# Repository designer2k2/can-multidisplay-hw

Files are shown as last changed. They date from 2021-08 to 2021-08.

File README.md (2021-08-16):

# can-multidisplay-hw
Displaying and measuring automotive related values, with CAN, GPS and more

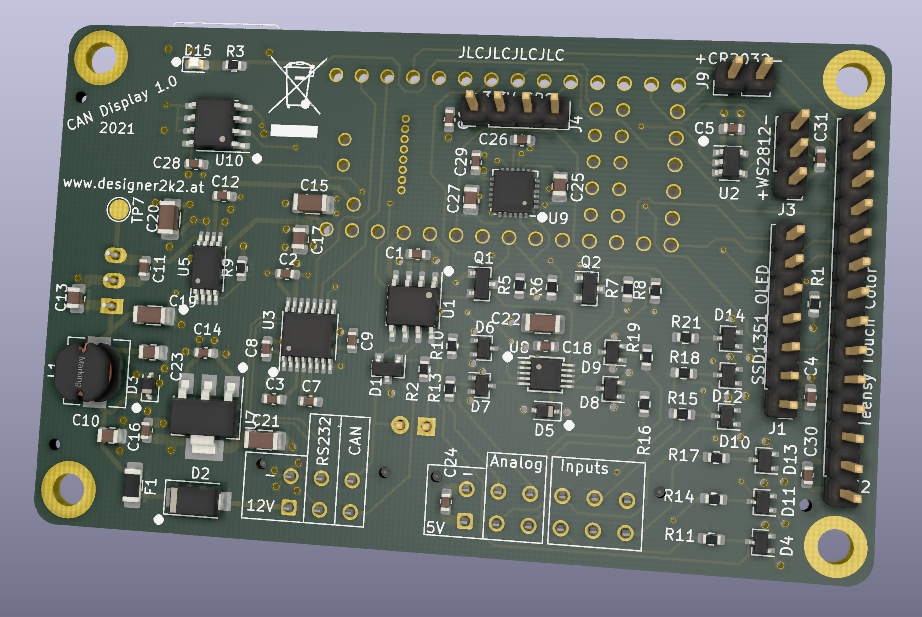
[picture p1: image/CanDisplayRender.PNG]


Software: https://github.com/designer2k2/can-multidisplay

## Features:

* Teensy 4 Microcontroller https://www.pjrc.com/store/teensy40.html
* 12V -> 5V Power supply with TPS2113A voltage selector
* 3,3V Power supply
* RTC battery to support Teensy
* SD card slot, with flex cable to Teensy
* WS2812 level shifter 74AHCT1G125
* GPS serial port
* CAN transceiver SN65HVD232 with selectable 120Ohm resistor
* RS232 level shifter MAX3232
* MPU-6050  Six-Axis (Gyro + Accelerometer)
* I2C Levelshifter to 5V
* TMP75AIDR I2C Temperature sensor
* 4 channel 12Bit ADC ADS1015IDGS
* 6 protected inputs
* SSD1351 OLED  Interface
* ILI9341 + XPT2046 Touch display Interface

PCB is made in KiCad and parts selected to have it produced by JLCPCB

## Images:

PCB Backside:

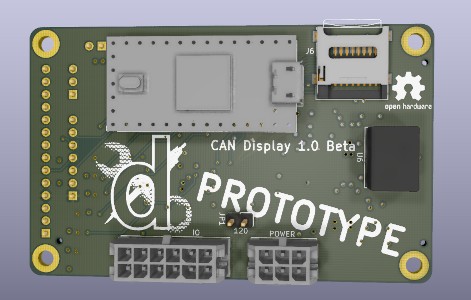
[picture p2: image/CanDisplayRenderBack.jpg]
PCB Backside


3D Rendering with Display, GPS and RGB LED:

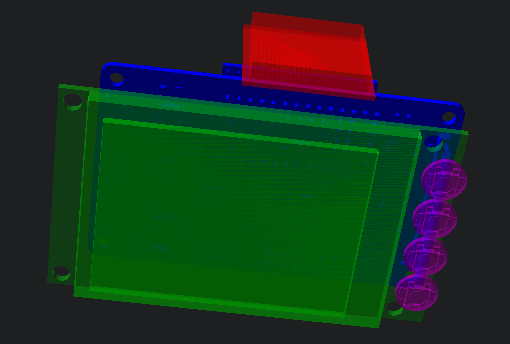
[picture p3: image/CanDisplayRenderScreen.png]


Display running:

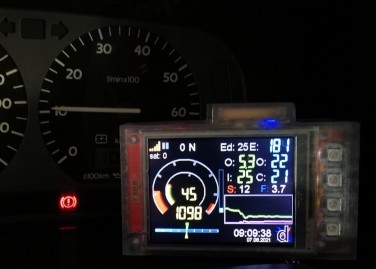
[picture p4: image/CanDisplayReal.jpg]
Display running


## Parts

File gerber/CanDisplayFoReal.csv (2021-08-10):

Comment | Designator | Footprint | LCSC
100n | C1,C2,C3,C4,C5,C6,C7,C8,C9,C11,C12,C14,C16,C18,C24,C26,C28,C29,C30,C31 | Capacitor_SMD:C_0603_1608Metric | C14663
2.2u | C10,C13 | Capacitor_SMD:C_0805_2012Metric | C49217
10u | C15,C19,C20,C21,C22 | Capacitor_SMD:C_1206_3216Metric | C13585
10n | C17,C23,C25 | Capacitor_SMD:C_0805_2012Metric | C1710
2.2n | C27 | Capacitor_SMD:C_0805_2012Metric | C28260
SZNUP2105L | D1 | Package_TO_SOT_SMD:SOT-23 | C233494
LED | D15 | LED_SMD:LED_0603_1608Metric | C2286
SK34 | D2 | Diode_SMD:D_SMA | C65008
24V | D3 | Diode_SMD:D_SOD-323 | C463816
5.1V | D5 | Diode_SMD:D_SOD-323 | C85392
BAT54SW | D4,D6,D7,D8,D9,D10,D11,D12,D13,D14 | Package_TO_SOT_SMD:SOT-323_SC-70 | C78260
Polyfuse | F1 | Fuse:Fuse_1206_3216Metric_Castellated | C70082
SmallDisp | J1 | Connector_PinHeader_2.54mm:PinHeader_1x07_P2.54mm_Vertical
BigDisp | J2 | Connector_PinHeader_2.54mm:PinHeader_1x14_P2.54mm_Vertical
WS2812 | J3 | Connector_PinHeader_2.54mm:PinHeader_1x03_P2.54mm_Vertical
GPS | J4 | Connector_PinHeader_2.54mm:PinHeader_1x04_P2.54mm_Vertical
Main Connect | J5 | Connector_Molex:Molex_Micro-Fit_3.0_43045-0612_2x03_P3.00mm_Vertical
Micro_SD_Card | J6 | Connector_Card:microSD_HC_Wuerth_693072010801
I/O | J8 | Connector_Molex:Molex_Micro-Fit_3.0_43045-1212_2x06_P3.00mm_Vertical
Batt | J9 | Connector_PinHeader_2.54mm:PinHeader_1x02_P2.54mm_Vertical
120CAN | JP1 | Connector_PinHeader_2.54mm:PinHeader_1x02_P2.54mm_Vertical
68uH | L1 | Inductor_SMD:L_6.3x6.3_H3 | C86662
BSS138 | Q1,Q2 | Package_TO_SOT_SMD:SOT-23 | C52895
100 | R1 | Resistor_SMD:R_0603_1608Metric | C22775
1k | R10,R11,R13,R14,R15,R16,R17,R18,R19,R21 | Resistor_SMD:R_0603_1608Metric | C21190
120 | R2,R3 | Resistor_SMD:R_0603_1608Metric | C22787
10k | R5,R6,R7,R8 | Resistor_SMD:R_0603_1608Metric | C25804
500 | R9 | Resistor_SMD:R_0603_1608Metric | C22808
TestPoint | TP5,TP7 | TestPoint:TestPoint_Pad_D2.0mm
SN65HVD232 | U1 | Package_SO:SOIC-8_3.9x4.9mm_P1.27mm | C30530
TMP75AIDR | U10 | Package_SO:SOIC-8_3.9x4.9mm_P1.27mm | C30389
74AHCT1G125 | U2 | Package_TO_SOT_SMD:SOT-23-5 | C12494
MAX3232 | U3 | Package_SO:TSSOP-16_4.4x5mm_P0.65mm | C19767
Teensy4.0 | U4 | teensy:Teensy40_SMT
TPS2113A | U5 | Package_SO:TSSOP-8_4.4x3mm_P0.65mm | C130052
R-78HE5.0-0.3 | U6 | Converter_DCDC:Converter_DCDC_RECOM_R-78E-0.5_THT
AMS1117-3.3 | U7 | Package_TO_SOT_SMD:SOT-223-3_TabPin2 | C6186
ADS1015IDGS | U8 | Package_SO:TSSOP-10_3x3mm_P0.5mm | C193969
MPU-6050 | U9 | Sensor_Motion:InvenSense_QFN-24_4x4mm_P0.5mm | C24112

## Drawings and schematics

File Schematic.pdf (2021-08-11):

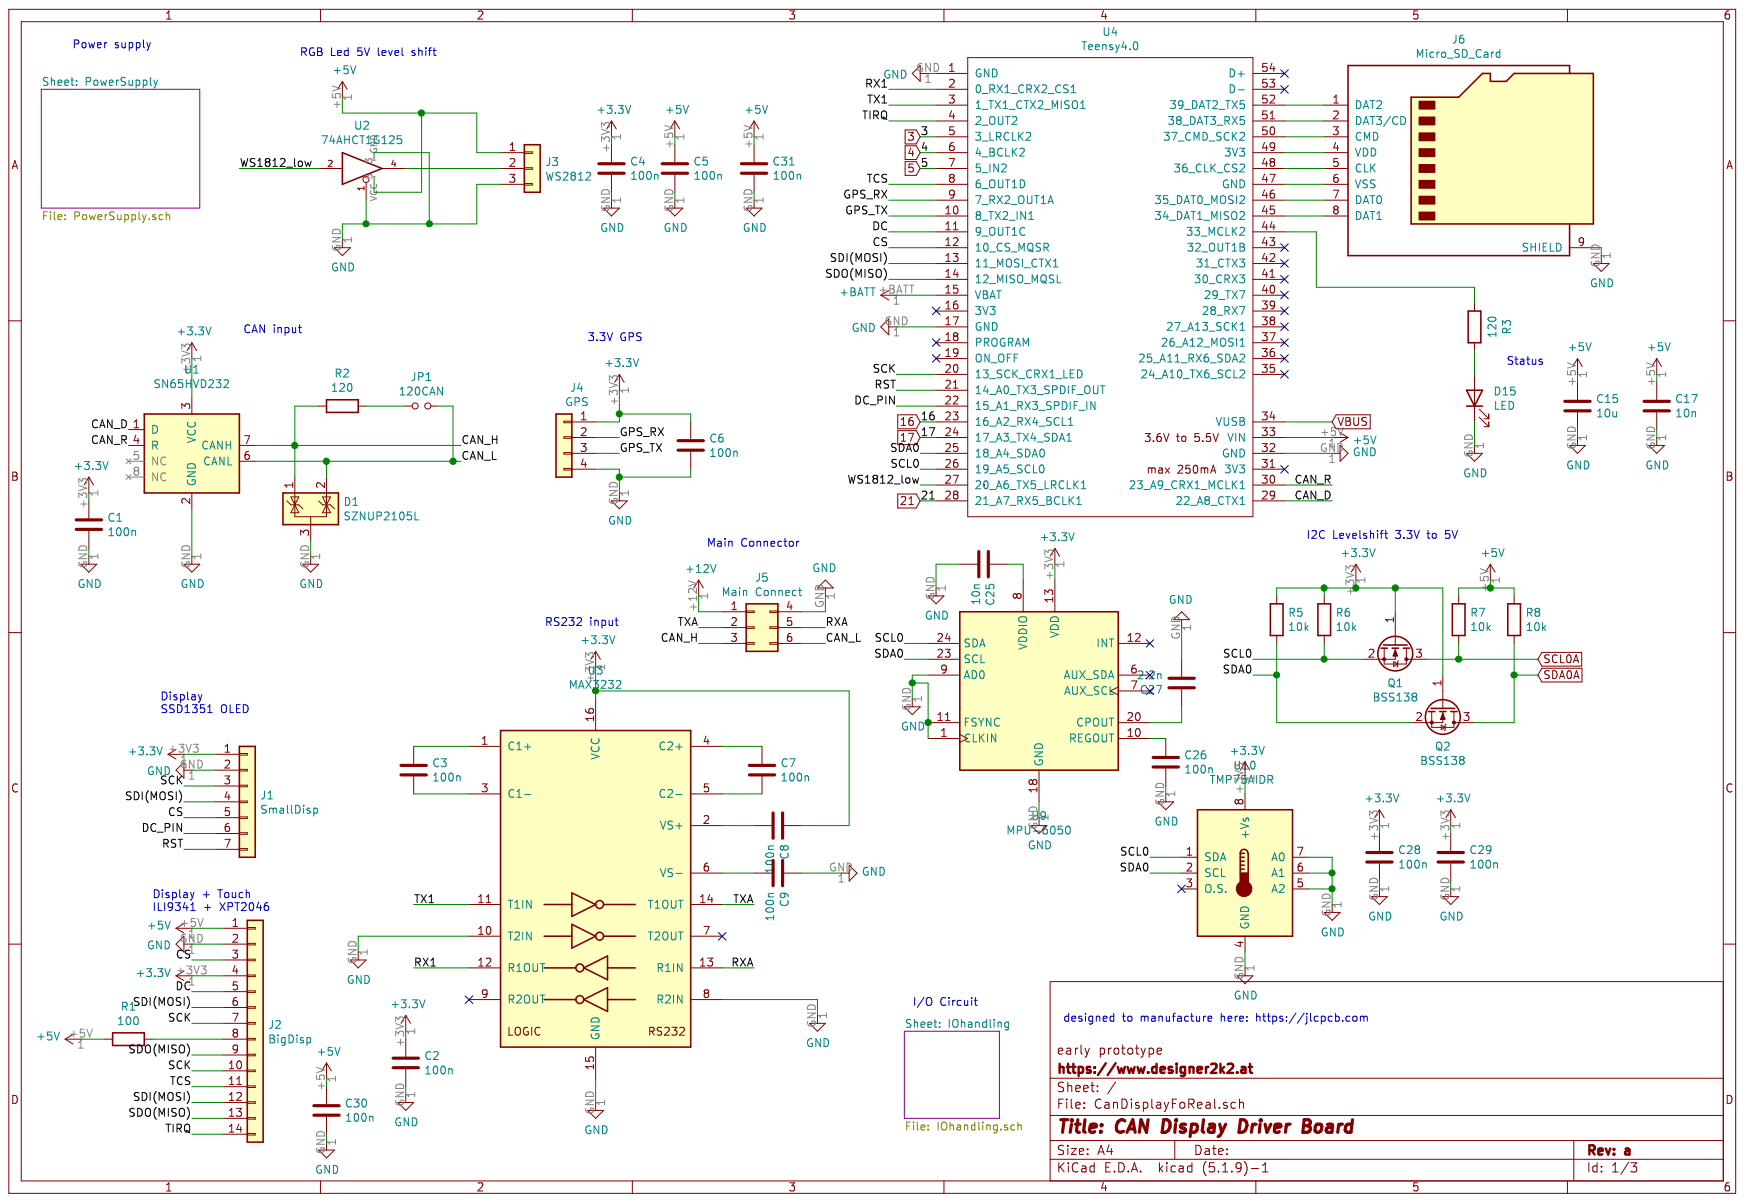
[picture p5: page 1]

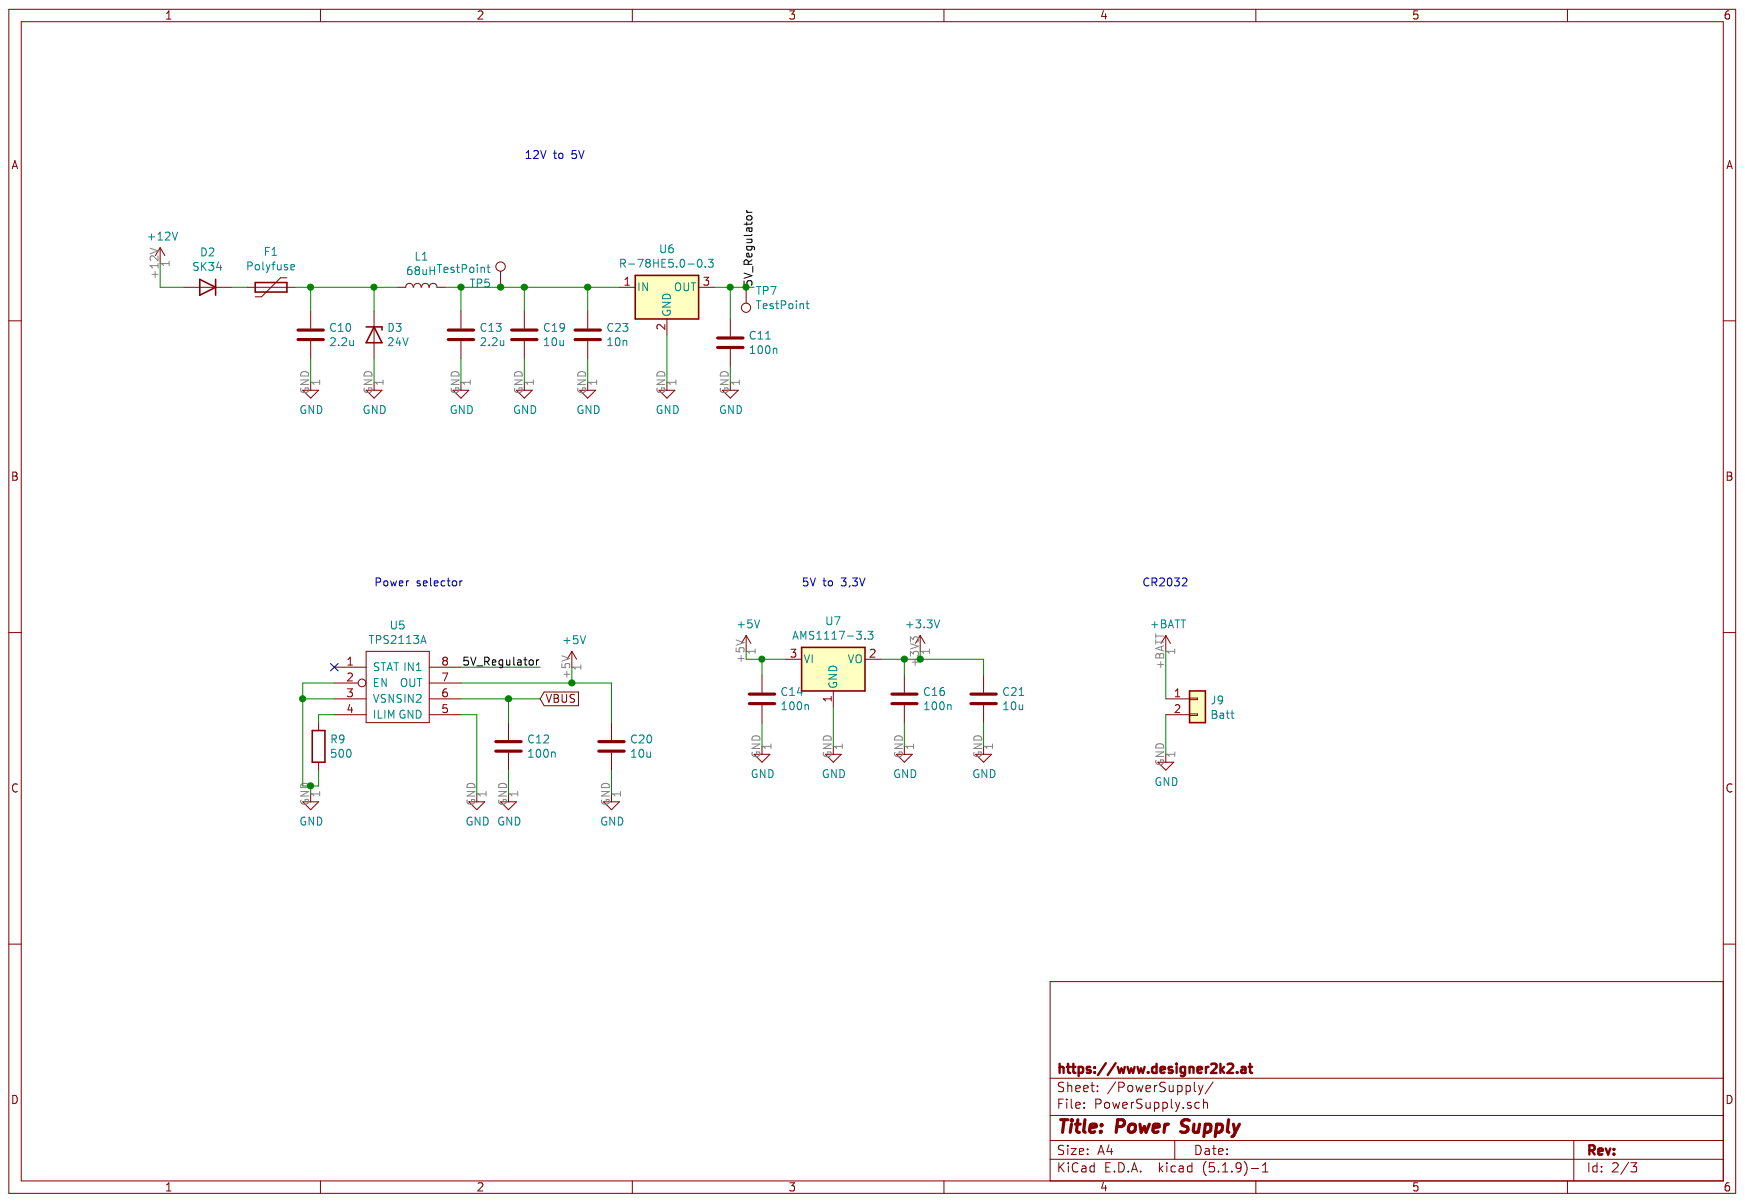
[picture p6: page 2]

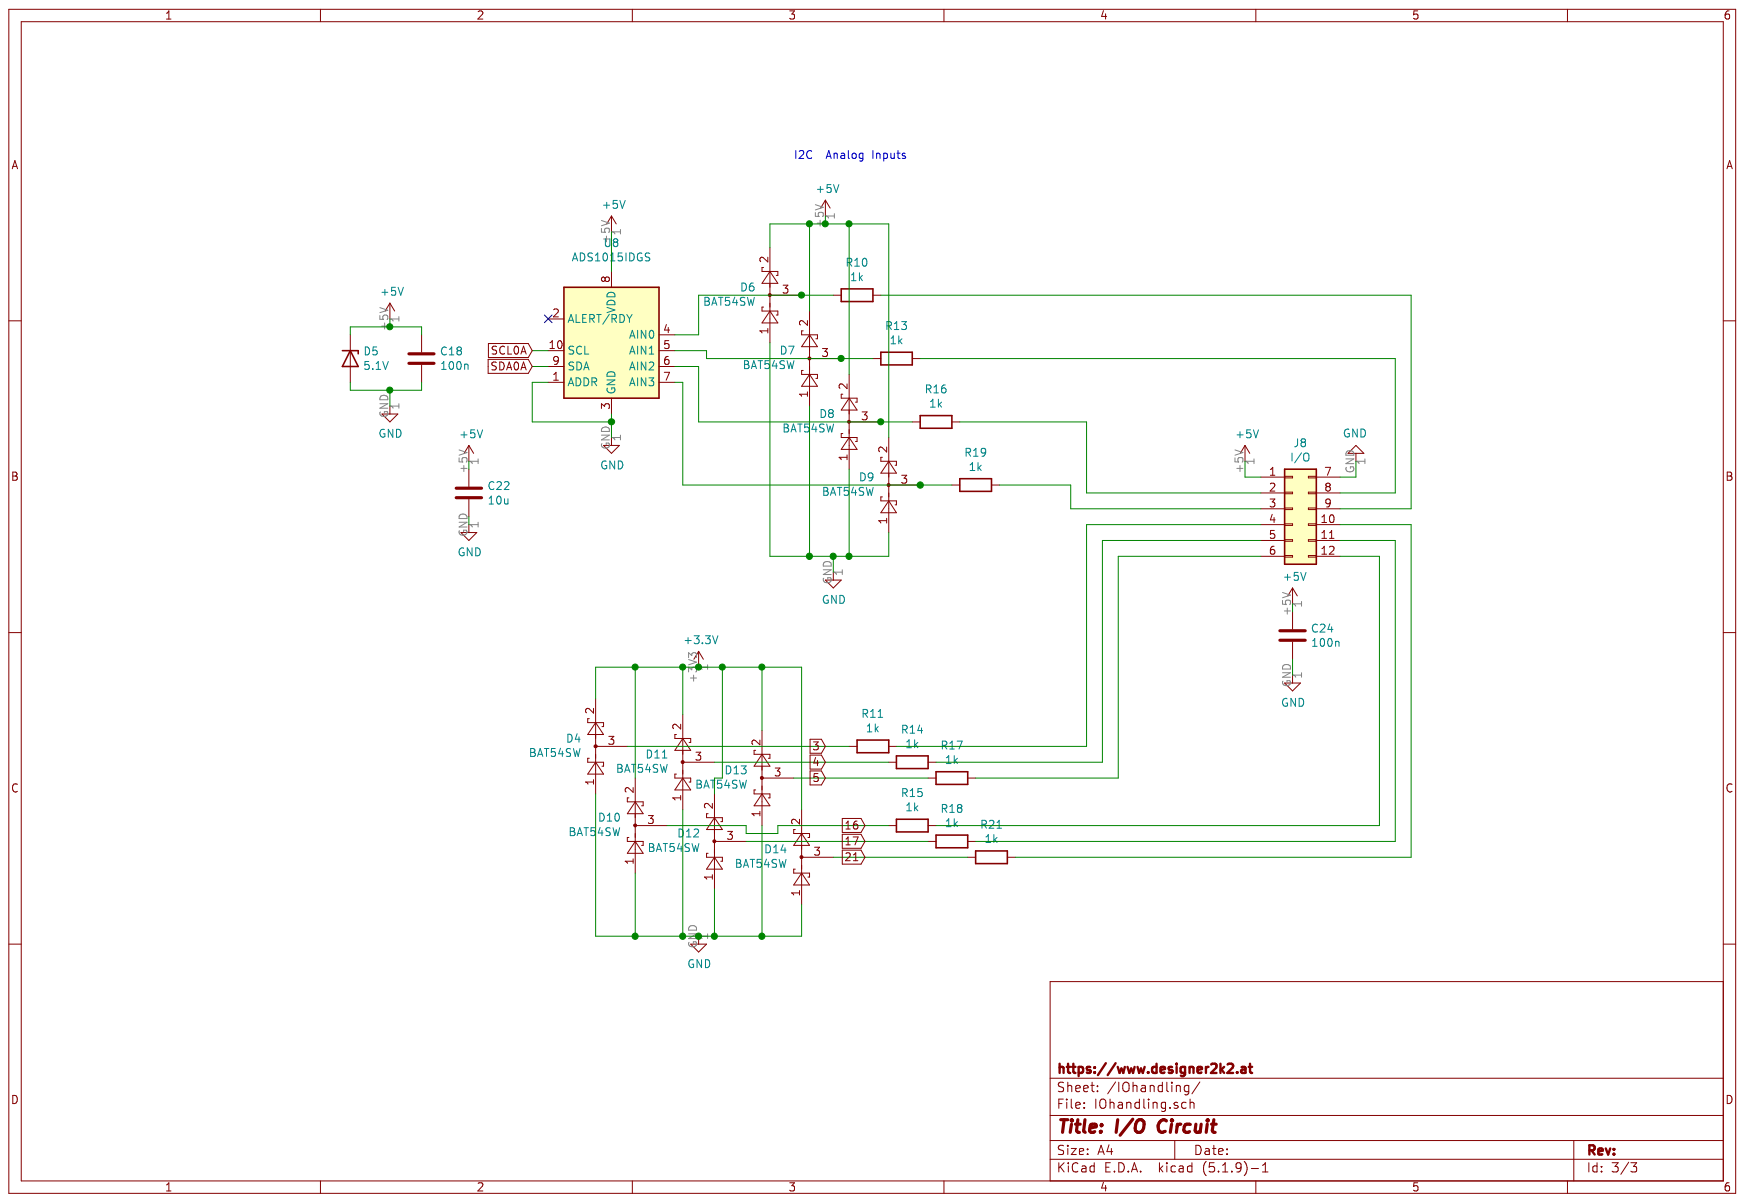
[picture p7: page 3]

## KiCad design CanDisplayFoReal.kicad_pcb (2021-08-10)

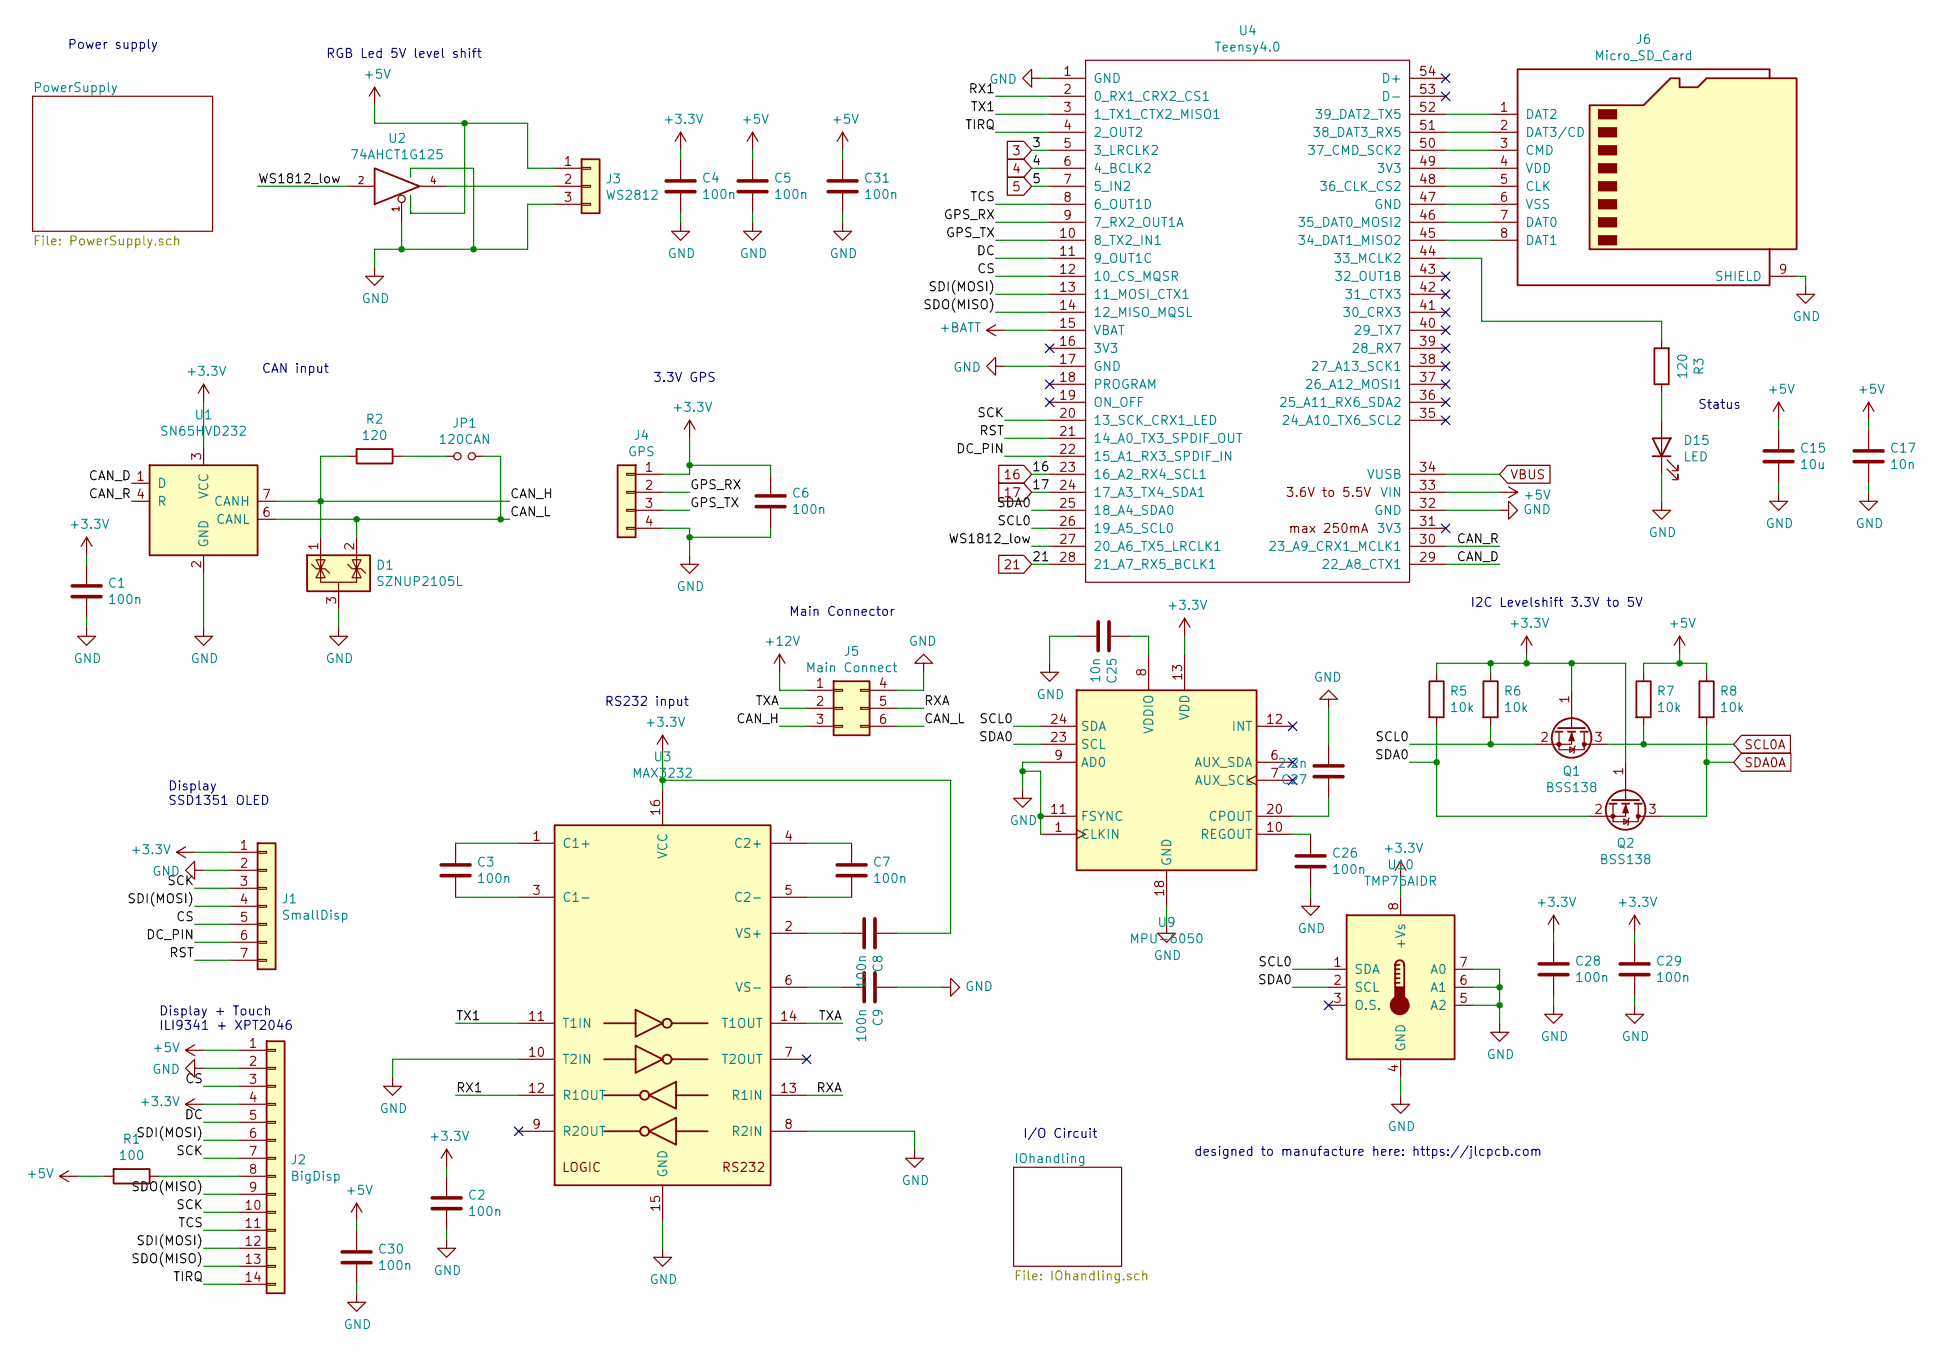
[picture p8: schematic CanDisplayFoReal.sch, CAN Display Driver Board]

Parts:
C1, C2, C3, C4, C5, C6, C7, C8, C9, C26, C28, C29, C30, C31: 100n; C_0603_1608Metric; JLCPCB C14663
C15: 10u; C_1206_3216Metric; JLCPCB C13585
C17, C25: 10n; C_0805_2012Metric; JLCPCB C1710
C27: 2.2n; C_0805_2012Metric; JLCPCB C28260
D1: SZNUP2105L; SOT-23; JLCPCB C233494
D15: LED; LED_0603_1608Metric; JLCPCB C2286
J1: SmallDisp; PinHeader_1x07_P2.54mm_Vertical
J2: BigDisp; PinHeader_1x14_P2.54mm_Vertical
J3: WS2812; PinHeader_1x03_P2.54mm_Vertical
J4: GPS; PinHeader_1x04_P2.54mm_Vertical
J5: Main Connect; Molex_Micro-Fit_3.0_43045-0612_2x03_P3.00mm_Vertical
J6: Micro_SD_Card; microSD_HC_Wuerth_693072010801
JP1: 120CAN; PinHeader_1x02_P2.54mm_Vertical
Q1, Q2: BSS138; SOT-23; JLCPCB C52895
R1: 100; R_0603_1608Metric; JLCPCB C22775
R2, R3: 120; R_0603_1608Metric; JLCPCB C22787
R5, R6, R7, R8: 10k; R_0603_1608Metric; JLCPCB C25804
U1: SN65HVD232; SOIC-8_3.9x4.9mm_P1.27mm; JLCPCB C30530
U2: 74AHCT1G125; SOT-23-5; JLCPCB C12494
U3: MAX3232; TSSOP-16_4.4x5mm_P0.65mm; JLCPCB C19767
U4: Teensy4.0; Teensy40_SMT
U9: MPU-6050; InvenSense_QFN-24_4x4mm_P0.5mm; JLCPCB C24112
U10: TMP75AIDR; SOIC-8_3.9x4.9mm_P1.27mm; JLCPCB C30389

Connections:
3: U4.5 (3_LRCLK2); also elsewhere on the board
4: U4.6 (4_BCLK2); also elsewhere on the board
5: U4.7 (5_IN2); also elsewhere on the board
16: U4.23 (16_A2_RX4_SCL1); also elsewhere on the board
17: U4.24 (17_A3_TX4_SDA1); also elsewhere on the board
21: U4.28 (21_A7_RX5_BCLK1); also elsewhere on the board
+3V3: C1.1, C2.1, C4.1, C6.1, C8.1, C28.1, C29.1, J1.1, J2.4, J4.1, Q1.1 (G), Q2.1 (G), R5.1, R6.1, U1.3 (VCC), U3.16 (VCC), U9.13 (VDD), U10.8 (+Vs); also elsewhere on the board
+5V: C5.1, C15.1, C17.1, C30.1, C31.1, J2.1, J3.1, R1.2, R7.1, R8.1, U2.5 (VCC), U4.33 (VIN); also elsewhere on the board
+12V: J5.1; also elsewhere on the board
+BATT: U4.15 (VBAT); also elsewhere on the board
/CAN_D: U1.1 (D), U4.29 (22_A8_CTX1)
/CAN_H: D1.1 (K), J5.3, R2.2, U1.7 (CANH)
/CAN_L: D1.2 (K), J5.6, JP1.2, U1.6 (CANL)
/CAN_R: U1.4 (R), U4.30 (23_A9_CRX1_MCLK1)
/CS: J1.5, J2.3, U4.12 (10_CS_MQSR)
/DC: J2.5, U4.11 (9_OUT1C)
/DC_PIN: J1.6, U4.22 (15_A1_RX3_SPDIF_IN)
/GPS_RX: J4.2, U4.9 (7_RX2_OUT1A)
/GPS_TX: J4.3, U4.10 (8_TX2_IN1)
/RST: J1.7, U4.21 (14_A0_TX3_SPDIF_OUT)
/RX1: U3.12 (R1OUT), U4.2 (0_RX1_CRX2_CS1)
/RXA: J5.5, U3.13 (R1IN)
/SCK: J1.3, J2.7, J2.10, U4.20 (13_SCK_CRX1_LED)
/SCL0: Q1.2 (S), R6.2, U4.26 (19_A5_SCL0), U9.24 (SDA), U10.1 (SDA)
/SDA0: Q2.2 (S), R5.2, U4.25 (18_A4_SDA0), U9.23 (SCL), U10.2 (SCL)
/SDI(MOSI): J1.4, J2.6, J2.12, U4.13 (11_MOSI_CTX1)
/SDO(MISO): J2.9, J2.13, U4.14 (12_MISO_MQSL)
/TCS: J2.11, U4.8 (6_OUT1D)
/TIRQ: J2.14, U4.4 (2_OUT2)
/TX1: U3.11 (T1IN), U4.3 (1_TX1_CTX2_MISO1)
/TXA: J5.2, U3.14 (T1OUT)
/WS1812_low: U2.2, U4.27 (20_A6_TX5_LRCLK1)
GND: C1.2, C2.2, C4.2, C5.2, C6.2, C9.1, C15.2, C17.2, C25.2, C26.2, C27.2, C28.2, C29.2, C30.2, C31.2, D1.3 (A), D15.1 (K), J1.2, J2.2, J3.3, J4.4, J5.4, J6.9 (SHIELD), U1.2 (GND), U2.1, U2.3 (GND), U3.8 (R2IN), U3.10 (T2IN), U3.15 (GND), U4.1 (GND), U4.17 (GND), U4.32 (GND), U9.1 (CLKIN), U9.9 (AD0), U9.11 (FSYNC), U9.18 (GND), U10.4 (GND), U10.5 (A2), U10.6 (A1), U10.7 (A0); also elsewhere on the board
unnamed: C3.1, U3.1 (C1+)
unnamed: C3.2, U3.3 (C1-)
unnamed: C7.1, U3.4 (C2+)
unnamed: C7.2, U3.5 (C2-)
unnamed: C8.2, U3.2 (VS+)
unnamed: C9.2, U3.6 (VS-)
unnamed: C25.1, U9.8 (VDDIO)
unnamed: C26.1, U9.10 (REGOUT)
unnamed: C27.1, U9.20 (CPOUT)
unnamed: D15.2 (A), R3.1
unnamed: J2.8, R1.1
unnamed: J3.2, U2.4
unnamed: J6.1 (DAT2), U4.52 (39_DAT2_TX5)
unnamed: J6.2 (DAT3/CD), U4.51 (38_DAT3_RX5)
unnamed: J6.3 (CMD), U4.50 (37_CMD_SCK2)
unnamed: J6.4 (VDD), U4.49 (3V3)
unnamed: J6.5 (CLK), U4.48 (36_CLK_CS2)
unnamed: J6.6 (VSS), U4.47 (GND)
unnamed: J6.7 (DAT0), U4.46 (35_DAT0_MOSI2)
unnamed: J6.8 (DAT1), U4.45 (34_DAT1_MISO2)
unnamed: JP1.1, R2.1
unnamed: R3.2, U4.44 (33_MCLK2)
SCL0A: Q1.3 (D), R7.2; also elsewhere on the board
SDA0A: Q2.3 (D), R8.2; also elsewhere on the board
VBUS: U4.34 (VUSB); also elsewhere on the board

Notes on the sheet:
designed to manufacture here: https://jlcpcb.com
Display SSD1351 OLED
RGB Led 5V level shift
CAN input
3.3V GPS
RS232 input
Power supply
I2C Levelshift 3.3V to 5V
Main Connector
I/O Circuit
Display + Touch ILI9341 + XPT2046
Status

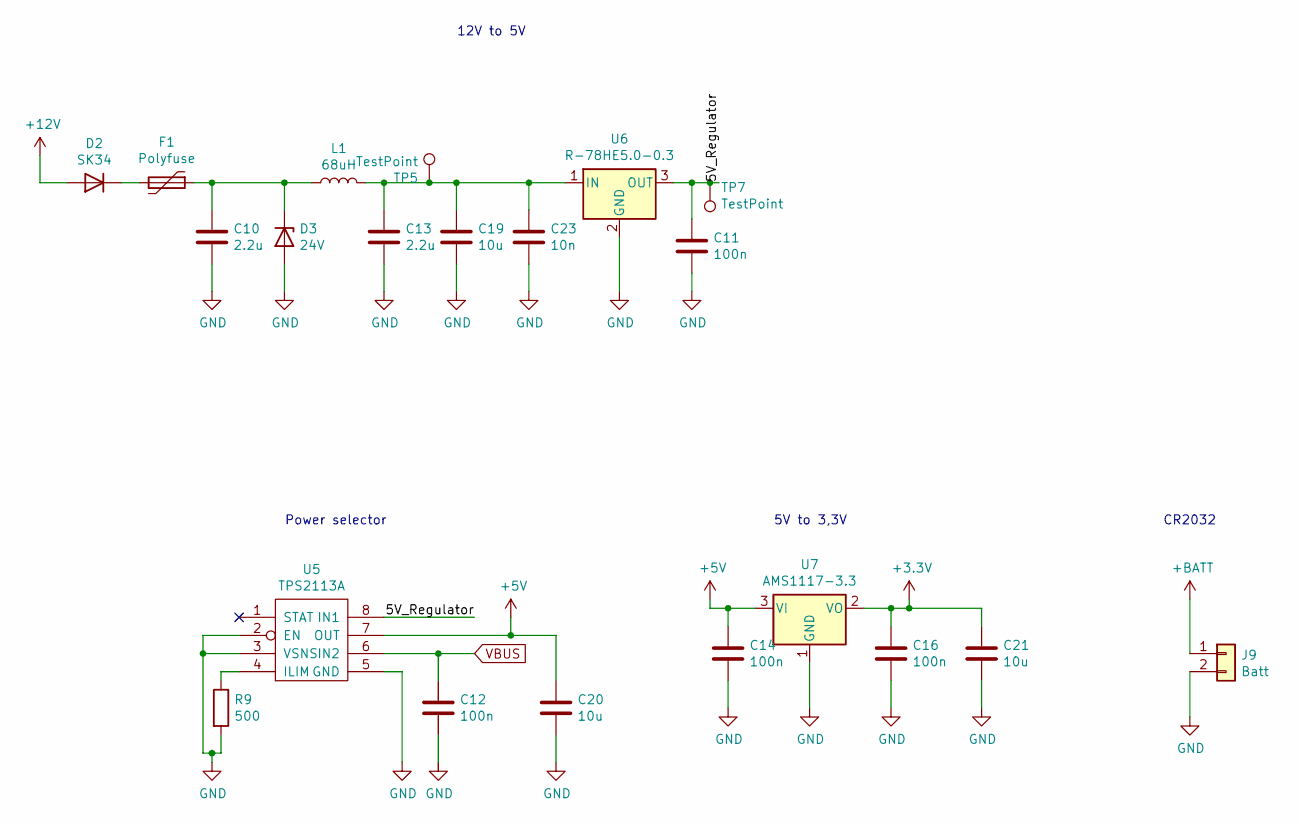
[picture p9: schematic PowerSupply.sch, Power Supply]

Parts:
C10, C13: 2.2u; C_0805_2012Metric; JLCPCB C49217
C11, C12, C14, C16: 100n; C_0603_1608Metric; JLCPCB C14663
C19, C20, C21: 10u; C_1206_3216Metric; JLCPCB C13585
C23: 10n; C_0805_2012Metric; JLCPCB C1710
D2: SK34; D_SMA; JLCPCB C65008
D3: 24V; D_SOD-323; JLCPCB C463816
F1: Polyfuse; Fuse_1206_3216Metric_Castellated; JLCPCB C70082
J9: Batt; PinHeader_1x02_P2.54mm_Vertical
L1: 68uH; L_6.3x6.3_H3; JLCPCB C86662
R9: 500; R_0603_1608Metric; JLCPCB C22808
TP5, TP7: TestPoint; TestPoint_Pad_D2.0mm
U5: TPS2113A; TSSOP-8_4.4x3mm_P0.65mm; JLCPCB C130052
U6: R-78HE5.0-0.3; Converter_DCDC_RECOM_R-78E-0.5_THT
U7: AMS1117-3.3; SOT-223-3_TabPin2; JLCPCB C6186

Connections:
+3V3: C16.1, C21.1, U7.2 (VO); also elsewhere on the board
+5V: C14.1, C20.1, U5.7 (OUT), U7.3 (VI); also elsewhere on the board
+12V: D2.2 (A); also elsewhere on the board
+BATT: J9.1; also elsewhere on the board
/PowerSupply/5V_Regulator: C11.1, TP7.1, U5.8 (IN1), U6.3 (OUT)
GND: C10.2, C11.2, C12.2, C13.2, C14.2, C16.2, C19.2, C20.2, C21.2, C23.2, D3.2 (A), J9.2, R9.2, U5.2 (EN), U5.3 (VSNS), U5.5 (GND), U6.2 (GND), U7.1 (GND); also elsewhere on the board
unnamed: C10.1, D3.1 (K), F1.1, L1.1
unnamed: C13.1, C19.1, C23.1, L1.2, TP5.1, U6.1 (IN)
unnamed: D2.1 (K), F1.2
unnamed: R9.1, U5.4 (ILIM)
VBUS: C12.1, U5.6 (IN2); also elsewhere on the board

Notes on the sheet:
12V to 5V
Power selector
5V to 3,3V
CR2032

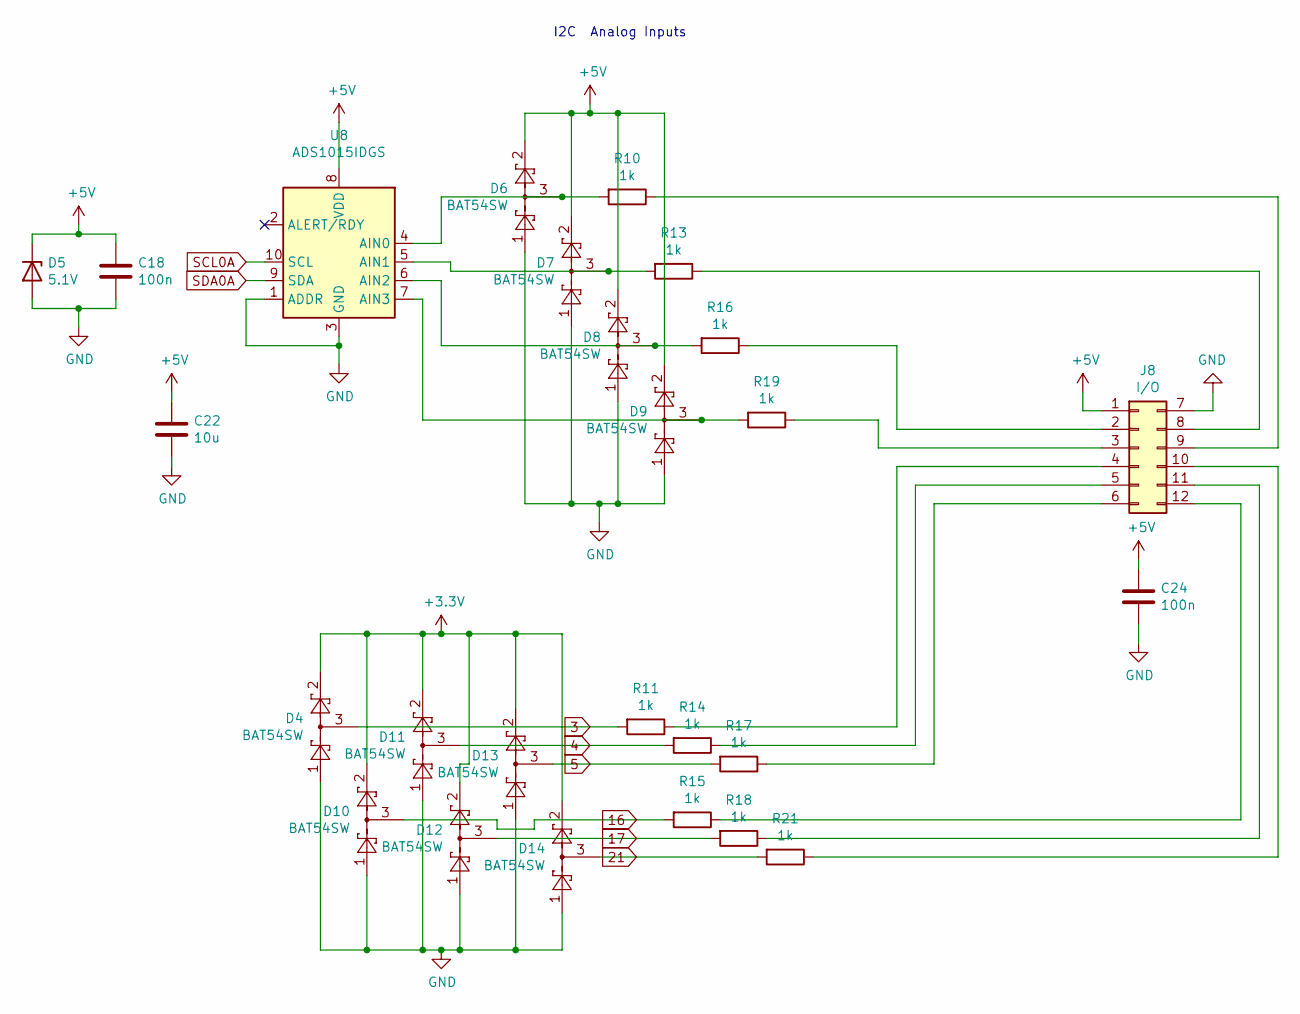
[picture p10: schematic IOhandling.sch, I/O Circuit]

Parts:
C18, C24: 100n; C_0603_1608Metric; JLCPCB C14663
C22: 10u; C_1206_3216Metric; JLCPCB C13585
D4, D6, D7, D8, D9, D10, D11, D12, D13, D14: BAT54SW; SOT-323_SC-70; JLCPCB C78260
D5: 5.1V; D_SOD-323; JLCPCB C85392
J8: I/O; Molex_Micro-Fit_3.0_43045-1212_2x06_P3.00mm_Vertical
R10, R11, R13, R14, R15, R16, R17, R18, R19, R21: 1k; R_0603_1608Metric; JLCPCB C21190
U8: ADS1015IDGS; TSSOP-10_3x3mm_P0.5mm; JLCPCB C193969

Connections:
3: D4.3, R11.2; also elsewhere on the board
4: D11.3, R14.2; also elsewhere on the board
5: D13.3, R17.2; also elsewhere on the board
16: D10.3, R15.2; also elsewhere on the board
17: D12.3, R18.2; also elsewhere on the board
21: D14.3, R21.2; also elsewhere on the board
+3V3: D4.2, D10.2, D11.2, D12.2, D13.2, D14.2; also elsewhere on the board
+5V: C18.1, C22.1, C24.1, D5.1 (K), D6.2, D7.2, D8.2, D9.2, J8.1, U8.8 (VDD); also elsewhere on the board
GND: C18.2, C22.2, C24.2, D4.1, D5.2 (A), D6.1, D7.1, D8.1, D9.1, D10.1, D11.1, D12.1, D13.1, D14.1, J8.7, U8.1 (ADDR), U8.3 (GND); also elsewhere on the board
unnamed: D6.3, R10.2, U8.4 (AIN0)
unnamed: D7.3, R13.2, U8.5 (AIN1)
unnamed: D8.3, R16.2, U8.6 (AIN2)
unnamed: D9.3, R19.2, U8.7 (AIN3)
unnamed: J8.2, R16.1
unnamed: J8.3, R19.1
unnamed: J8.4, R11.1
unnamed: J8.5, R14.1
unnamed: J8.6, R17.1
unnamed: J8.8, R13.1
unnamed: J8.9, R10.1
unnamed: J8.10, R21.1
unnamed: J8.11, R18.1
unnamed: J8.12, R15.1
SCL0A: U8.10 (SCL); also elsewhere on the board
SDA0A: U8.9 (SDA); also elsewhere on the board

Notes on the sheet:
I2C Analog Inputs

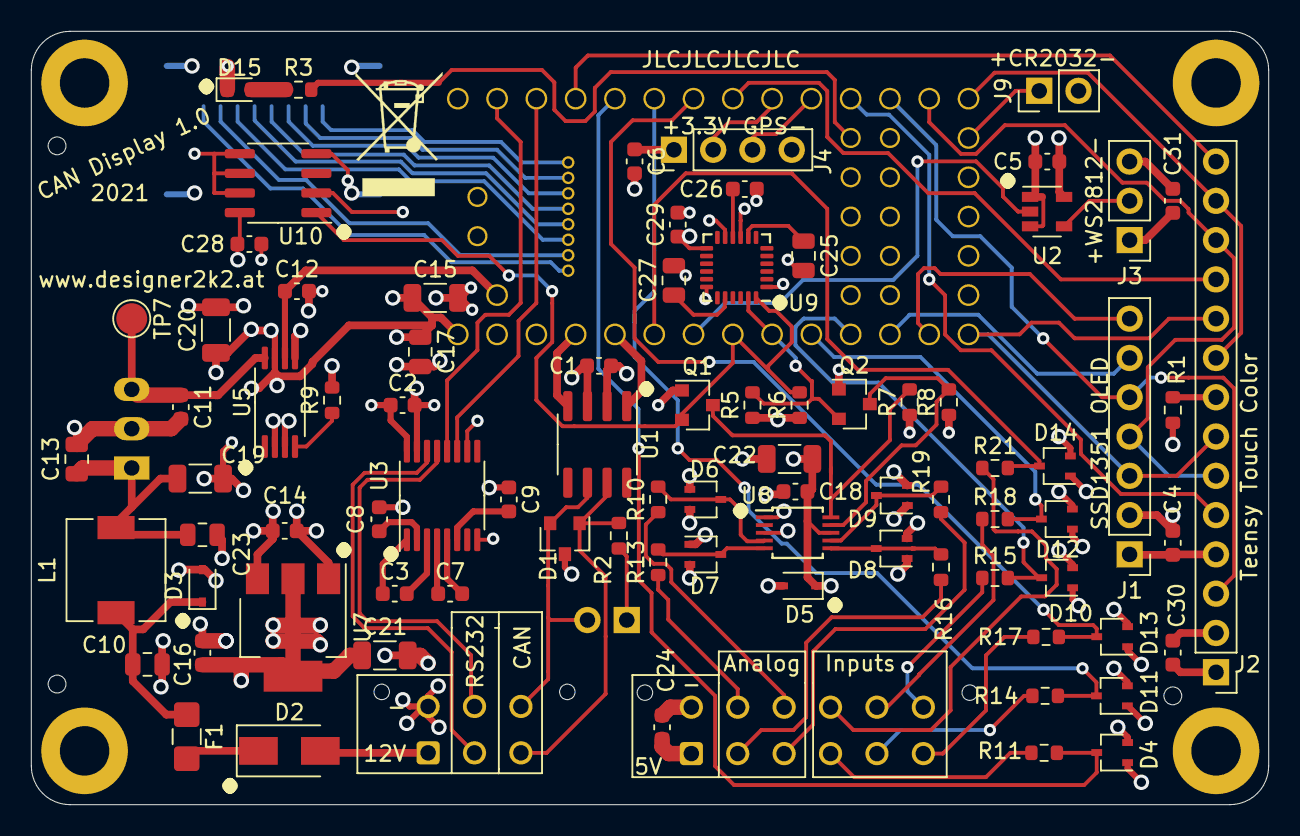
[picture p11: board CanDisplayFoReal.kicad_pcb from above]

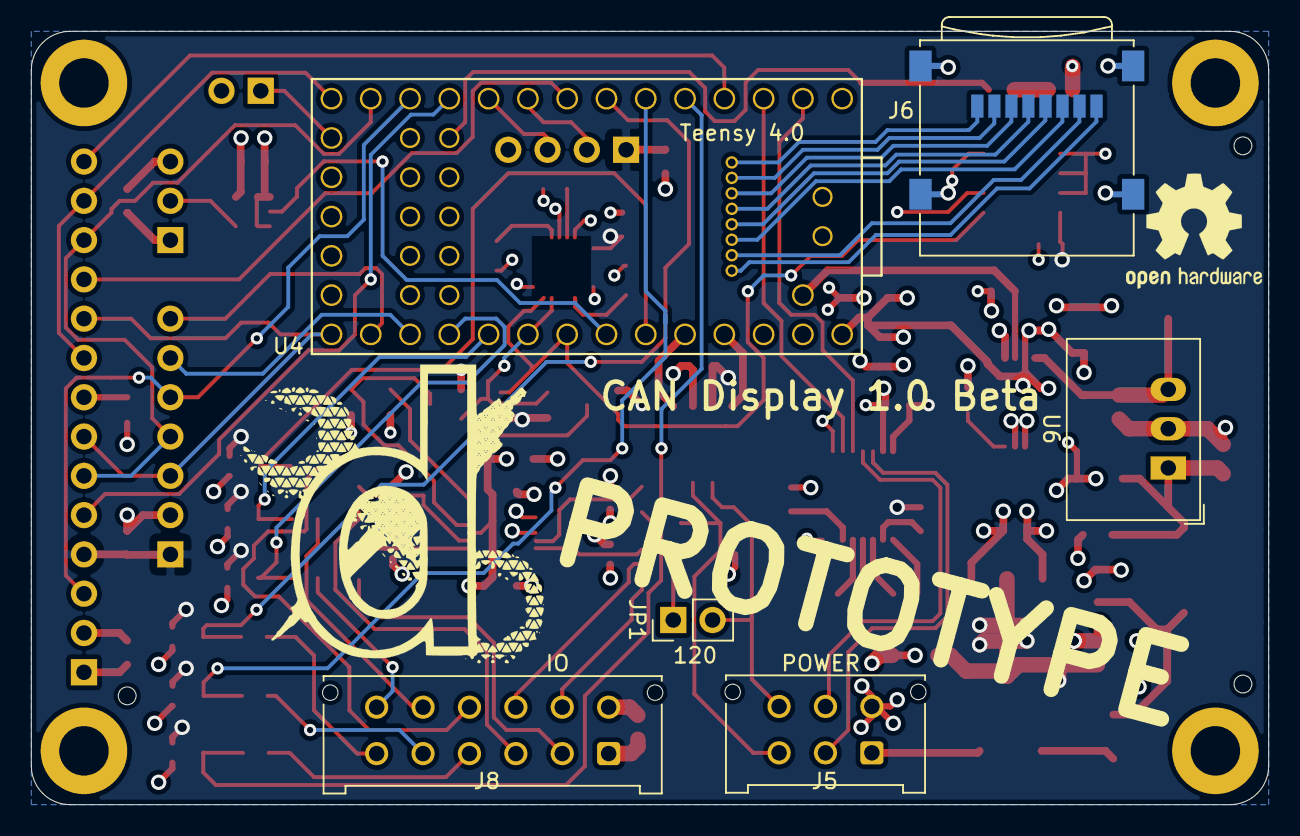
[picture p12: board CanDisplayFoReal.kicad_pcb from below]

Board: 4 copper layers, 80.0 x 50.0 mm, 88 parts (6 on the bottom side), 77 nets.

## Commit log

2021-08-10 initial hardware
    hardware as it was ordered
    [CanDisplayFoReal-B_Cu.gbr, CanDisplayFoReal-B_Mask.gbr, CanDisplayFoReal-B_Paste.gbr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]
2021-08-10 add ibom
    interactive BOM
2021-08-10 add BOM
    BOM used for ordering the pcb´s
    [CanDisplayFoReal.csv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]
2021-08-11 add Schematic pdf
